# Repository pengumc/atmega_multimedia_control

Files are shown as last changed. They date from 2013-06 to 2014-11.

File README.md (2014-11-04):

An atmega based usb hid consumer decive for volume, pause/play, next and previous functions
===========================================================================================

see also [http://www.pengurobotics.com/projects/media_controller](http://www.pengurobotics.com/projects/media_controller)

and [http://www.thingiverse.com/thing:126130](http://www.thingiverse.com/thing:126130) for the 3D files

Building the firmware
---------------------
you need the vusb files from 
https://github.com/obdev/v-usb or http://www.obdev.at/products/vusb/download.html

more specifically: the "usbdrv" folder needs to be copied to your cloned repository.

step by step example:

clone this repository

    git clone https://github.com/pengumc/atmega_multimedia_control

grab the vusb files    

    wget http://www.obdev.at/downloads/vusb/vusb-20121206.tar.gz

extract

    tar -xf vusb-20121206.tar.gz

cp the usbdrv folder to the cloned repository

    cp -r vusb-20121206/usbdrv atmega_multimedia_control/
    
build firmware

    cd atmega_multimedia_control
    make

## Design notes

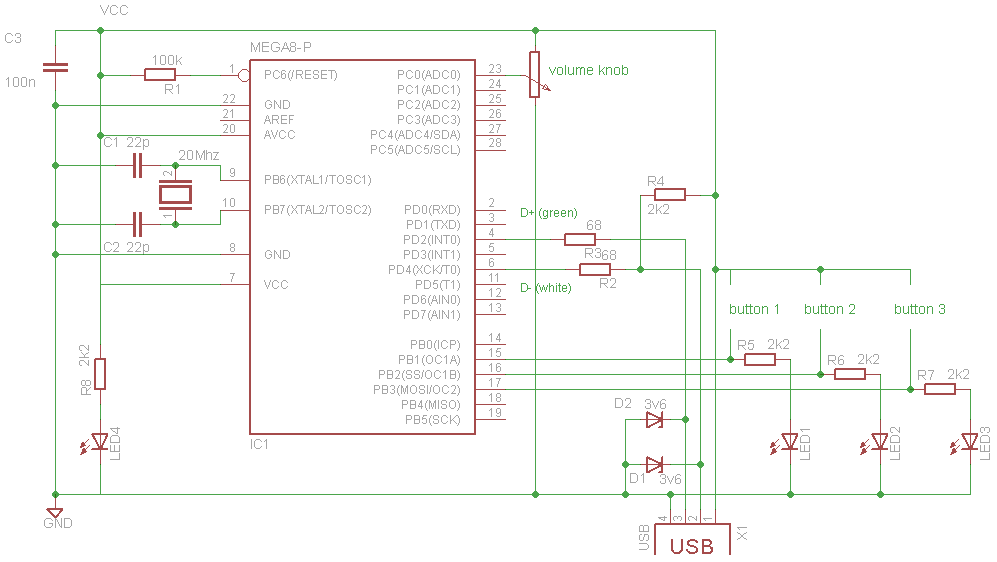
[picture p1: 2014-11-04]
circuit/atmega_multimedia_control.png

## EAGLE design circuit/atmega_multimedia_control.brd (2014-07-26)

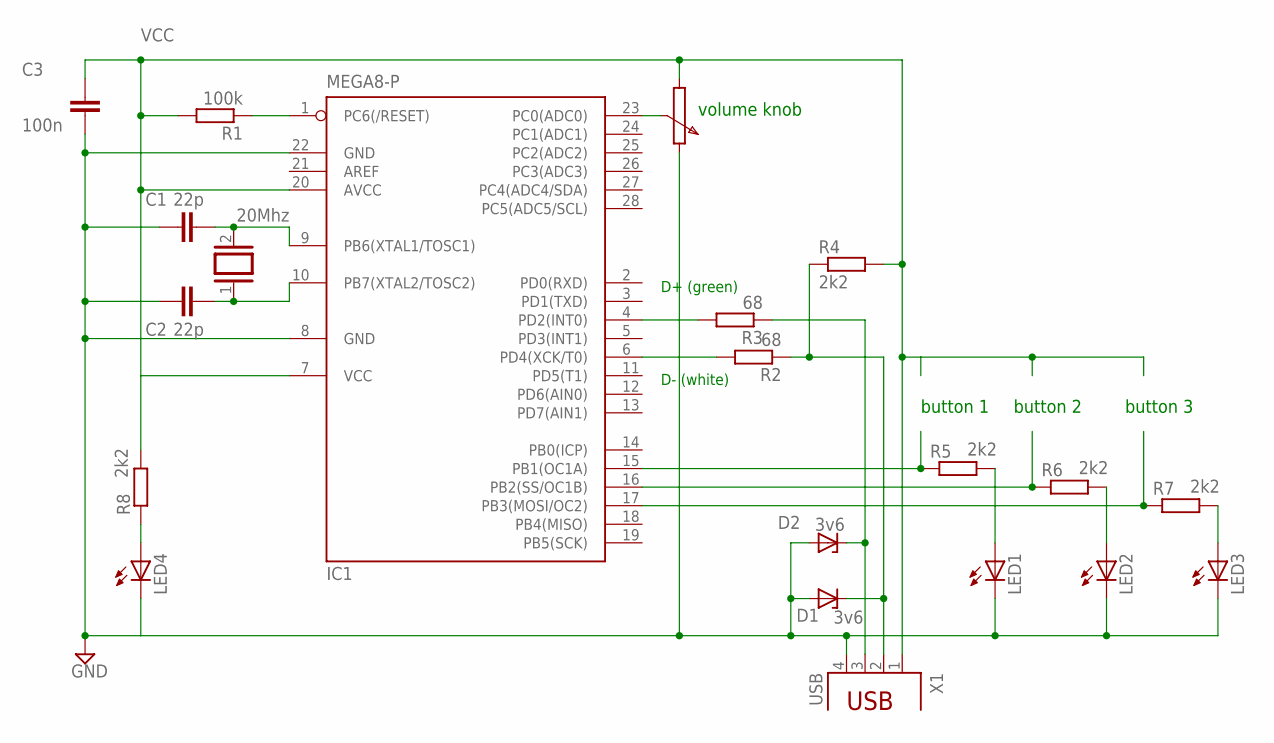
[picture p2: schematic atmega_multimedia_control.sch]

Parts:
C1, C2: 22p; C025-025X050
C3: 100n; C025-025X050
D1, D2: 3v6; DO34Z7
IC1: MEGA8-P; DIL28-3
LED1, LED2, LED3, LED4: LED3MM
Q1: 20Mhz; QS
R1: 100k; 0204/7
R2, R3: 68; 0204/7
R4, R5, R6, R7, R8: 2k2; 0204/7
X1: USB; PN61729

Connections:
GND: C1.1, C2.1, C3.1, D1.A, D2.A, IC1.8 (GND), IC1.22 (GND), LED1.K (C), LED2.K (C), LED3.K (C), LED4.K (C), X1.4
unnamed: IC1.1 (PC6(/RESET)), R1.1
unnamed: C1.2, IC1.9 (PB6(XTAL1/TOSC1)), Q1.2
unnamed: C2.2, IC1.10 (PB7(XTAL2/TOSC2)), Q1.1
unnamed: D2.C, R3.1, X1.3
unnamed: IC1.6 (PD4(XCK/T0)), R2.2
unnamed: IC1.4 (PD2(INT0)), R3.2
unnamed: IC1.15 (PB1(OC1A)), R5.1
unnamed: LED1.A, R5.2
unnamed: IC1.16 (PB2(SS/OC1B)), R6.1
unnamed: LED2.A, R6.2
unnamed: IC1.17 (PB3(MOSI/OC2)), R7.1
unnamed: LED3.A, R7.2
unnamed: LED4.A, R8.1
unnamed: D1.C, R2.1, R4.1, X1.2
VCC: C3.2, IC1.7 (VCC), IC1.20 (AVCC), R1.2, R4.2, R8.2, X1.1

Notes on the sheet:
button 1
button 2
button 3
volume knob
D+ (green)
D- (white)

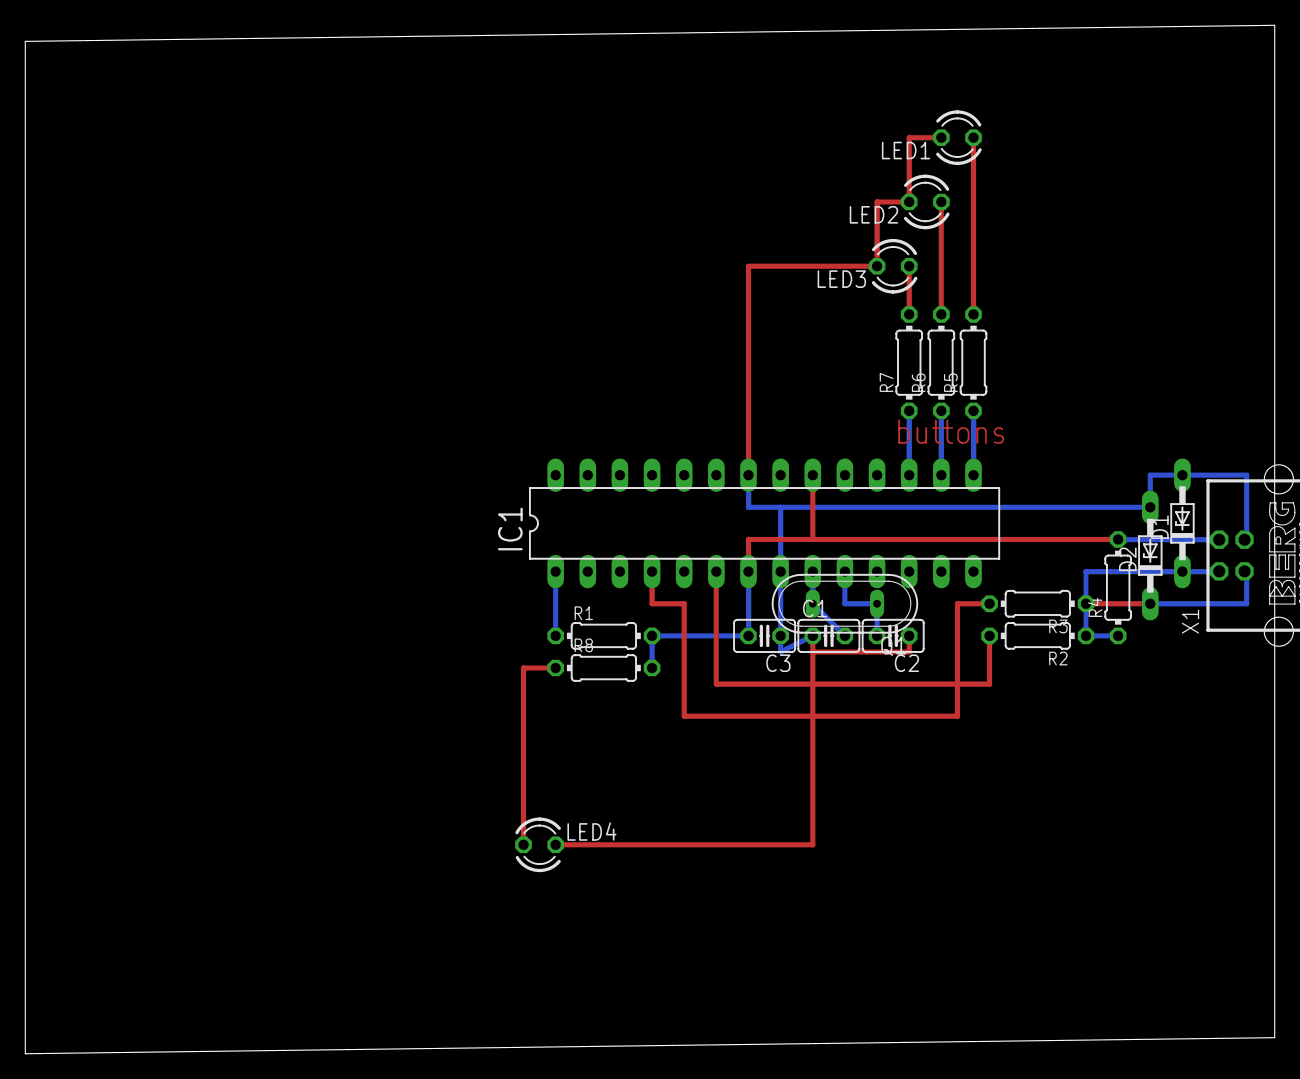
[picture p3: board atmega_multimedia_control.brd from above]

Board: 2 copper layers, 98.7 x 81.3 mm, 20 parts (0 on the bottom side), 16 nets.

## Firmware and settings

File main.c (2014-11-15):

//atmega multimedia controller
//Author: Michiel van der Coelen (michiel.van.der.coelen@gmail.com)
//Date: 2014-11

//MCU = atmega88
//F_CPU = 20000000 defined in makefile
//hfuse: DF 
//lfuse: E6
//efuse: 0

#include <avr/io.h>
#include <avr/interrupt.h>
#include <avr/pgmspace.h>
#include <avr/wdt.h>
#include <util/delay.h> 
#include "usbdrv.h"
#include "oddebug.h"
#include "requests.h"

//macros
#define SET(x,y) (x|=(1<<y))
#define CLR(x,y) (x&=(~(1<<y)))
#define CHK(x,y) (x&(1<<y)) 
#define TOG(x,y) (x^=(1<<y))
#define VOLUME_UP 0
#define VOLUME_DOWN 1
#define NEXT_TRACK 2
#define PREV_TRACK 3
#define PAUSE_TRACK 4
#define MAX_VOLUME 63
#define BUTTONPORT PINB
#define BUTTON_PREV PB1
#define BUTTON_PAUSE PB2
#define BUTTON_NEXT PB3


static uchar reportBuffer[1];    /* buffer for HID reports */
static uchar idleRate;           /* in 4 ms units */
static uchar msgBuffer;

static uchar button_states = 0;
#define STATE_NEXT 0
#define STATE_PREV 2
#define STATE_PAUSE 4

uchar changed = 0;
uchar adc_result = 0; 
uchar volume = MAX_VOLUME;
uchar first_adc = 1;
uchar filter = 0x80;  // filter state for adc

const PROGMEM char usbHidReportDescriptor[31] = {   /* USB report descriptor */
    0x05, 0x0C, // Usage Page (Consumer Devices)
    0x09, 0x01, // Usage (Consumer Control)
    0xA1, 0x01, // Collection (Application)
        0x15, 0x00, // Logical Minimum (0)
        0x25, 0x01, // Logical Maximum (1)
        0x09, 0xE9, // Usage (Volume Up)
        0x09, 0xEA, // Usage (Volume Down)
        0x09, 0xb5, // Usage (scan Next Track)
        0x09, 0xb6, // Usage (scan Previous Track)
        0x09, 0xcd, // Usage (media play/pause) ?undocumented?
        0x75, 0x01, // Report Size (1)
        0x95, 0x05, // Report Count (5)
        0x81, 0x06, // Input (Data, Variable, rel)
        0x95, 0x03, // Report Count (3)
        0x81, 0x07, // Input (Constant)
    0xC0 // End Collection
};


 
 uchar	usbFunctionSetup(uchar data[8]){
    usbRequest_t    *rq = (void *)data;
    usbMsgPtr = reportBuffer;
    if((rq->bmRequestType & USBRQ_TYPE_MASK) == USBRQ_TYPE_CLASS){
        if(rq->bRequest == USBRQ_HID_GET_REPORT){
            return sizeof(reportBuffer);
        }else if(rq->bRequest == USBRQ_HID_GET_IDLE){
            usbMsgPtr = &idleRate;
            return 1;
        }else if(rq->bRequest == USBRQ_HID_SET_IDLE){
            idleRate = rq->wValue.bytes[1];
        }
    }else{ // some debug stuff that's left in.
        if(rq->bRequest == USBRQ_GET_LAST_ADC_RESULT){
            msgBuffer = adc_result;
            usbMsgPtr = &msgBuffer;
            return 1;
        }
    }
	return 0;
}

void filter_volume(uchar adc_value) {
    // Explanation without math:
    // --------------------------
    // compare the adc_value against the current volume.
    // Each time the adc_value is higher, increase a filter counter.
    // when it's lower, decrease the counter, and if it's equal, converge it to 
    // its midvalue of 0x80.
    //
    // once the filter counter reaches 0x01 or 0xFF, decrease or increase the
    // volume by 1, and discard 40 from the filter counter so we need
    // another 40 at least, before we increase the volume again
    //
    // example adc values (without noise):
    //
    //    |‾‾‾‾‾‾‾‾‾‾‾‾‾‾‾‾‾‾‾‾‾‾
    //    |
    // ___|
    //          time --->
    //
    //
    //
    // result of filter:
    //          
    //              /‾‾‾‾‾‾‾‾‾‾‾‾
    //             /
    // ___________/
    //         time --->
    //
    // Changing the filter top and bottom values (1 and 0xff) will change the
    // delay before the slope starts. Changing the amount that's discarded (40)
    // will change the angle of the slope.
    
    if (volume > adc_value) {
        if (filter > 0x00) {
            --filter;
        } else {
            filter = 40; // move 40 closer to 0x80
            if (volume > 0x01) {  // up and down should be equally spaced
                --volume;
                SET(reportBuffer[0], VOLUME_UP); // reversed because soldering.
                changed = 1;
            }
        }
    } else if (volume < adc_value) {
        if (filter < 0xFF) {
             ++filter;
        } else {
            filter = 215; // move 40 closer to 0x80
            if (volume < MAX_VOLUME) {
                ++volume;
                SET(reportBuffer[0], VOLUME_DOWN);
                changed = 1;
            }
        }
    } else {  // volume == adc_value
        if (filter > 0x80) {
            --filter;
        } else if (filter < 0x80) {
            ++filter;
        }
    }
}


int main(){
    SET(DDRC, PC5);// led
    // connect usb
    wdt_enable(WDTO_1S);
    usbInit();
    usbDeviceDisconnect();
    register uint8_t i=0;
    while(--i){
        wdt_reset();
        _delay_ms(1);
    }
    usbDeviceConnect();
    sei();
    // setup ports, timers, and init variables.
    ADMUX = (1<<REFS0) | (1<<ADLAR); // ref = avcc, left adjust result
    ADCSRA = (1<<ADEN) | (1<<ADSC) | 7; // turn on adc, prescale 128 -> 6.4 us conversion t
    DIDR0 = (1<<ADC0D); // digital input disabled for adc0 
    TCCR0B = 5; // prescale TC0 1024, 20 MHz -> 50 ns * 1024 * 255 = 13.056 ms
    reportBuffer[0] = 0x00; // usb report buffer
    SET(PORTC, PC5); // status led on
    while(1){
        usbPoll(); // check for usb communications
        wdt_reset(); // reset watchdog timer
        if(CHK(TIFR0, TOV0)){ // check if 13 ms have passed already
            TIFR0 = 1<<TOV0;    // clear timer overflow flag
            TCNT0 = 0;          // reset timer
            // check button states
            // NEXT 
            if(CHK(BUTTONPORT, BUTTON_NEXT)){           // if it's down
                SET(button_states, STATE_NEXT);           // set current state to down
                if(CHK(button_states, (STATE_NEXT+1))){   // if previous state was down
                                                            // nothing changed, do nothing
                }else{                                    // else (something did change)
                    SET(reportBuffer[0], NEXT_TRACK);       // send down state
                    SET(button_states, (STATE_NEXT+1));     // update previous state
                    changed = 1;                            // set flag to send report
                }
            }else{                                      // else, button is up
                CLR(button_states, STATE_NEXT);           // set current state to up
                if(CHK(button_states, (STATE_NEXT+1))){   // if previous was down
                    CLR(reportBuffer[0], NEXT_TRACK);       // send up state
                    CLR(button_states, (STATE_NEXT+1));     // update previous state
                    changed = 1;                            // set flag to send report
                }else{                                    // else button already was up
                                                            // nothing changed, do nothing
                }
            }
            // PREVIOUS
            if(CHK(BUTTONPORT, BUTTON_PREV)){         
                SET(button_states, STATE_PREV);       
                if(CHK(button_states, (STATE_PREV+1))){ 
                                                      
                }else{                                
                    SET(reportBuffer[0], PREV_TRACK);
                    SET(button_states, (STATE_PREV+1)); 
                    changed = 1;
                }
            }else{                                    
                CLR(button_states, STATE_PREV);       
                if(CHK(button_states, (STATE_PREV+1))){ 
                    CLR(reportBuffer[0], PREV_TRACK);
                    CLR(button_states, (STATE_PREV+1)); 
                    changed = 1;
                }else{
                                                      
                }
            }
            // PAUSE
            if(CHK(BUTTONPORT, BUTTON_PAUSE)){         
                SET(button_states, STATE_PAUSE);       
                if(CHK(button_states, (STATE_PAUSE+1))){ 
                                                      
                }else{                                
                    SET(reportBuffer[0], PAUSE_TRACK);
                    SET(button_states, (STATE_PAUSE+1)); 
                    changed = 1;
                }
            }else{                                    
                CLR(button_states, STATE_PAUSE);       
                if(CHK(button_states, (STATE_PAUSE+1))){ 
                    CLR(reportBuffer[0], PAUSE_TRACK);
                    CLR(button_states, (STATE_PAUSE+1)); 
                    changed = 1;
                }else{
                                                      
                }
            }
            
        }
        // new adc
        if (!CHK(ADCSRA, ADSC)) {
            adc_result = (ADCH >> 2);
            SET(ADCSRA, ADIF);            // clear the conversion done flag
            SET(ADCSRA, ADSC);            // start the next conversion
            if (first_adc) {              // first conversion since startup?
                volume = adc_result;        // sync volume and adc_result
                first_adc = 0;              // next time won't be the first.
            } else {                      // else
                filter_volume(adc_result);  // filter our adc_result
            }
        }
        if(changed){ // something changed, send a report
            changed = 0;
            TIFR0 = 1<<TOV0;
            TCNT0 = 0;
            wdt_reset();
            usbSetInterrupt(reportBuffer, sizeof(reportBuffer)); // send report
            while(!usbInterruptIsReady()){} //wait till it's sent.
            // immediately sent a report that all buttons are up.
            reportBuffer[0] = 0x00; 
            usbSetInterrupt(reportBuffer, sizeof(reportBuffer));
        }
    } // while
} // main

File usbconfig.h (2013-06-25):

/* Name: usbconfig.h
 * Project: V-USB, virtual USB port for Atmel's(r) AVR(r) microcontrollers
 * Author: Christian Starkjohann
 * Creation Date: 2005-04-01
 * Tabsize: 4
 * Copyright: (c) 2005 by OBJECTIVE DEVELOPMENT Software GmbH
 * License: GNU GPL v2 (see License.txt), GNU GPL v3 or proprietary (CommercialLicense.txt)
 * This Revision: $Id: usbconfig-prototype.h 785 2010-05-30 17:57:07Z cs $
 */

#ifndef __usbconfig_h_included__
#define __usbconfig_h_included__

/*
General Description:
This file is an example configuration (with inline documentation) for the USB
driver. It configures V-USB for USB D+ connected to Port D bit 2 (which is
also hardware interrupt 0 on many devices) and USB D- to Port D bit 4. You may
wire the lines to any other port, as long as D+ is also wired to INT0 (or any
other hardware interrupt, as long as it is the highest level interrupt, see
section at the end of this file).
*/

/* ---------------------------- Hardware Config ---------------------------- */

#define USB_CFG_IOPORTNAME      D
/* This is the port where the USB bus is connected. When you configure it to
 * "B", the registers PORTB, PINB and DDRB will be used.
 */
#define USB_CFG_DMINUS_BIT      4
/* This is the bit number in USB_CFG_IOPORT where the USB D- line is connected.
 * This may be any bit in the port.
 */
#define USB_CFG_DPLUS_BIT       2
/* This is the bit number in USB_CFG_IOPORT where the USB D+ line is connected.
 * This may be any bit in the port. Please note that D+ must also be connected
 * to interrupt pin INT0! [You can also use other interrupts, see section
 * "Optional MCU Description" below, or you can connect D- to the interrupt, as
 * it is required if you use the USB_COUNT_SOF feature. If you use D- for the
 * interrupt, the USB interrupt will also be triggered at Start-Of-Frame
 * markers every millisecond.]
 */
#define USB_CFG_CLOCK_KHZ       (F_CPU/1000)
/* Clock rate of the AVR in kHz. Legal values are 12000, 12800, 15000, 16000,
 * 16500, 18000 and 20000. The 12.8 MHz and 16.5 MHz versions of the code
 * require no crystal, they tolerate +/- 1% deviation from the nominal
 * frequency. All other rates require a precision of 2000 ppm and thus a
 * crystal!
 * Since F_CPU should be defined to your actual clock rate anyway, you should
 * not need to modify this setting.
 */
#define USB_CFG_CHECK_CRC       0
/* Define this to 1 if you want that the driver checks integrity of incoming
 * data packets (CRC checks). CRC checks cost quite a bit of code size and are
 * currently only available for 18 MHz crystal clock. You must choose
 * USB_CFG_CLOCK_KHZ = 18000 if you enable this option.
 */

/* ----------------------- Optional Hardware Config ------------------------ */

/* #define USB_CFG_PULLUP_IOPORTNAME   D */
/* If you connect the 1.5k pullup resistor from D- to a port pin instead of
 * V+, you can connect and disconnect the device from firmware by calling
 * the macros usbDeviceConnect() and usbDeviceDisconnect() (see usbdrv.h).
 * This constant defines the port on which the pullup resistor is connected.
 */
/* #define USB_CFG_PULLUP_BIT          4 */
/* This constant defines the bit number in USB_CFG_PULLUP_IOPORT (defined
 * above) where the 1.5k pullup resistor is connected. See description
 * above for details.
 */

/* --------------------------- Functional Range ---------------------------- */
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

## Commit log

2013-06-25 start of circuit
    [atmega_multimedia_control.sch]
2013-06-28 updated circuit
    [atmega_multimedia_control.brd, atmega_multimedia_control.sch]
2013-06-30 3 buttons + know working
    undocumented usage 0xcd is for play/pause
2013-07-06 circuit and board done
    volume knob is missing from board. some led resistors still need proper
    placement, will sort that out during soldering
    [atmega_multimedia_control.brd, atmega_multimedia_control.sch]
2013-07-06 circuit image
2013-07-21 soldering done
    [atmega_multimedia_control.sch]
2013-07-31 visual updates
    [atmega_multimedia_control.sch]
2014-07-26 fixed schematic
    [atmega_multimedia_control.brd, atmega_multimedia_control.sch]
2014-11-15 filtered adc
